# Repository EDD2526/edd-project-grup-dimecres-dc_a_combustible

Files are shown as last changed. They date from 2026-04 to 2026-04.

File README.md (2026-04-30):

View this project on [CADLAB.io](https://cadlab.io/project/30189). 

# Projecte Combustible

>**Autors:** David Puges & Victor Donet
>**Versió: ** v.1.0.0 11/03/2026

----------

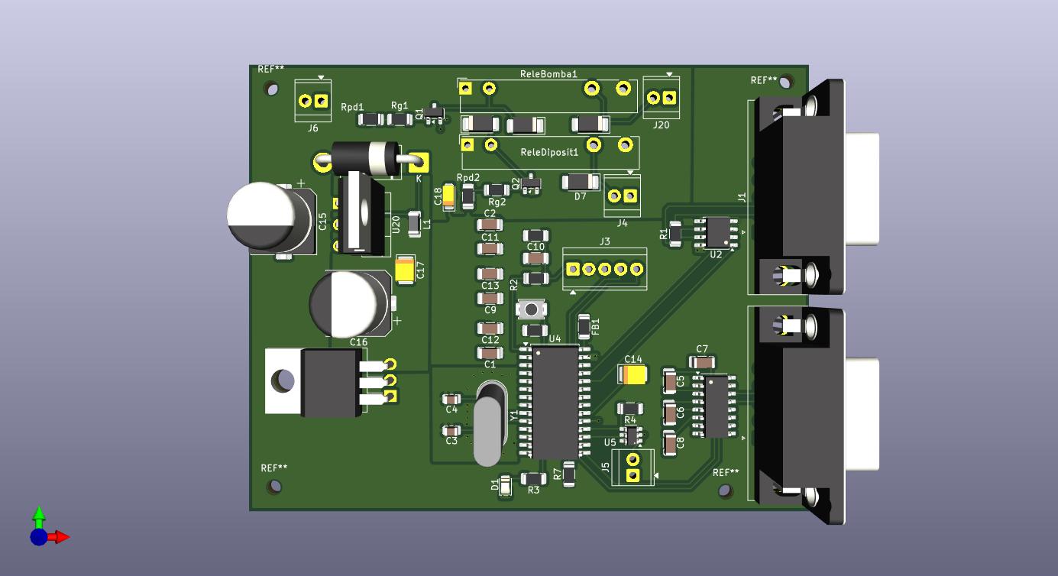
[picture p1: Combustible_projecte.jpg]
PCB 3D Render

*3D render of the Fuel Management Electronic Module designed in KiCad 9. 
The board integrates a PIC24HJ128GP502 microcontroller, CAN bus (MCP2562), 
RS232 (MAX3232), 12-bit I2C DAC (MCP4725), two 12V/6A power relays and a 
complete power management stage (buck LM2596 + LDO LM1117).*

----------
## Objectiu Descripció breu de l'objectiu del projecte.

L'objectiu del projecte és crear una pcb capaç de controlar el mecanisme de tancament de dipòsit del combustible d'un cotxe, controli el sensor de pressió de pneumàtics i el sensor digital de nivell de combustible i el funcionament de la bomba de combustible.

## Diagrama de blocs

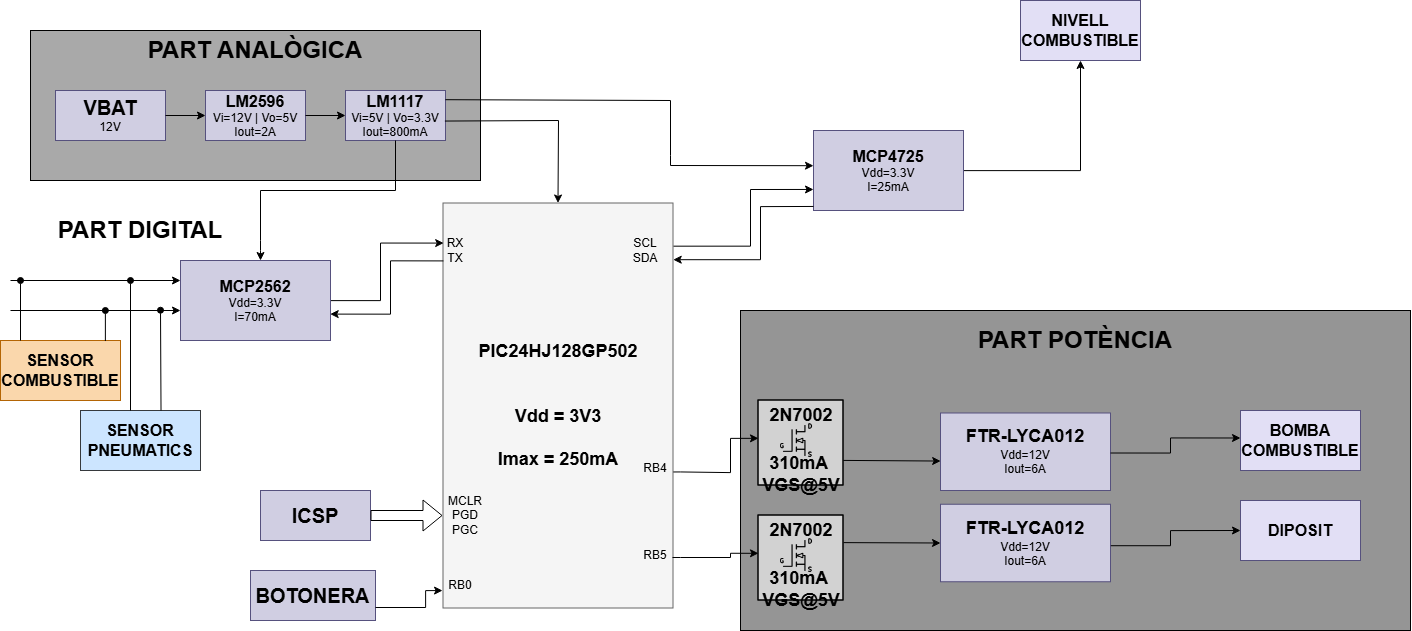
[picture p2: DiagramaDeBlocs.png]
Imatge Diagrama De Blocs


-----------

## Requisits / Especificacions

  - Una etapa regulador de tensió per alimentar tots el components de la placa.
  - Tenir un microcontrolador encarregat del control de la nostra placa.
  - Tenir una connexió BUS CAN, I2C.
  - Una comuniació USART per connectar el microcontrolador a aparells extern ja ve sigui un ordinador.
  - Tenir entrades com un boto per a que s'interección amb la placa.

-----------

## Components

| Descripci&#243; | Ref | Package |Datasheet | Prove&#239;dor | Unitats |
| --- | --- | --- | --- | --- | --- |
| Microcontrolador | PIC24HJ128GP502 | SOIC-28 |[Datasheet](https://ww1.microchip.com/downloads/aemDocuments/documents/OTH/ProductDocuments/DataSheets/70293G.pdf) | Mouser| 1x |
| XTAL-Ressonador | X49SM8MSD2SC | SMD |[Datasheet](https://www.lcsc.com/datasheet/C326536.pdf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) | [LCSC] | 1x |
| Regulador de tensió | LM1117 | SOT-223 | [Enllaç](https://www.ti.com/lit/ds/symlink/lm1117.pdf) | Mouser | 1 |
| Regulador de commutació | LM2596 | TO-220 / TO-263 | [Enllaç](https://www.ti.com/lit/ds/symlink/lm2596.pdf) |Mouser | 1 |
| Transceptor CAN | MCP2557 | SOIC-8  | [Enllaç](https://www.digikey.es/es/products/detail/microchip-technology/MCP2557FD-H-SN/6009299?productid=6009299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) | DigiKey | 1 |
| Convertidor DAC | MCP4725 | SOT-23-6 | [Enllaç](https://ww1.microchip.com/downloads/en/devicedoc/22039d.pdf) | DigiKey / Mouser | 1 |
| Relé | Fujitsu_FTR-LYAA005Y | SPST-Vertical | [Enllaç](https://www.fujitsu.com/sg/imagesgig5/ftr-ly.pdf) | Mouser | 2 |
| Díode protector | PMEG6030EP | Diode_SMD:D_SOD-128 | [Enllaç](https://www.vishay.com/docs/88516/1n5400.pdf) | Mouser | 2 |
| Pulsador reset | SKRKAEE020 | SW_Push_SPST_NO_Alps_SKRK | [Enllaç](https://www.mouser.es/datasheet/2/15/SKRK-1370789.pdf) | Mouser | 1 |
| Connector DB9 | DB9 PINS | DSUB-9 THT | [Enllaç](https://www.we-online.com/components/products/datasheet/61800925123.pdf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) | Digikey | 1 |
| Connector 01x02 | 61300211121 | PinHeader_1x02_P2.54mm_Vertical | [Enllaç](https://www.we-online.com/components/products/datasheet/61300211121.pdf) |Digikey | 4 |
| Connector ISCP | 61200621621 | PinHeader_2x03_P2.54mm_Vertical | [Enllaç](https://www.we-online.com/components/products/datasheet/61200621621.pdf) | Digikey | 1 |
| Connector Usart | 61300611121 | PinHeader_1x06_P2.54mm_Vertical | [Enllaç](https://www.we-online.com/components/products/datasheet/61300611121.pdf) | Digikey | 1 |
-----------

### Eines:

  * KiCad 9.0 o superior 

### Funcionalitats:

  - El mecanisme de tancament i obertura del dipòsit de combustible
  - Un sensor digital del nivell de combustible
  - El mecanisme que controli la bomba de combustible
  - Un sensor que ens avisi quan la pressió dels pneumàtics sigui baixa 

-----------

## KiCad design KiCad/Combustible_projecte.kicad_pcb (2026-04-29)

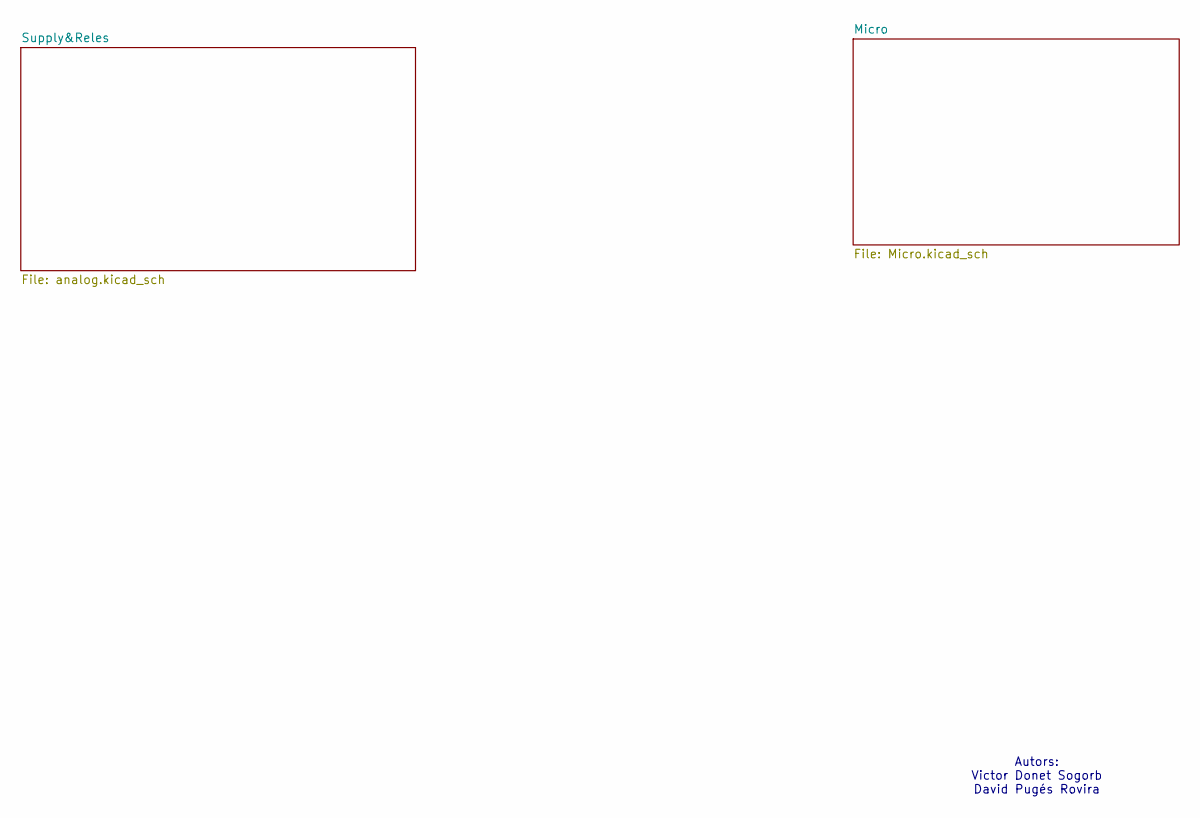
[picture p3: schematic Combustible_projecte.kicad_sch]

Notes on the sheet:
Autors: Victor Donet Sogorb David Pugés Rovira

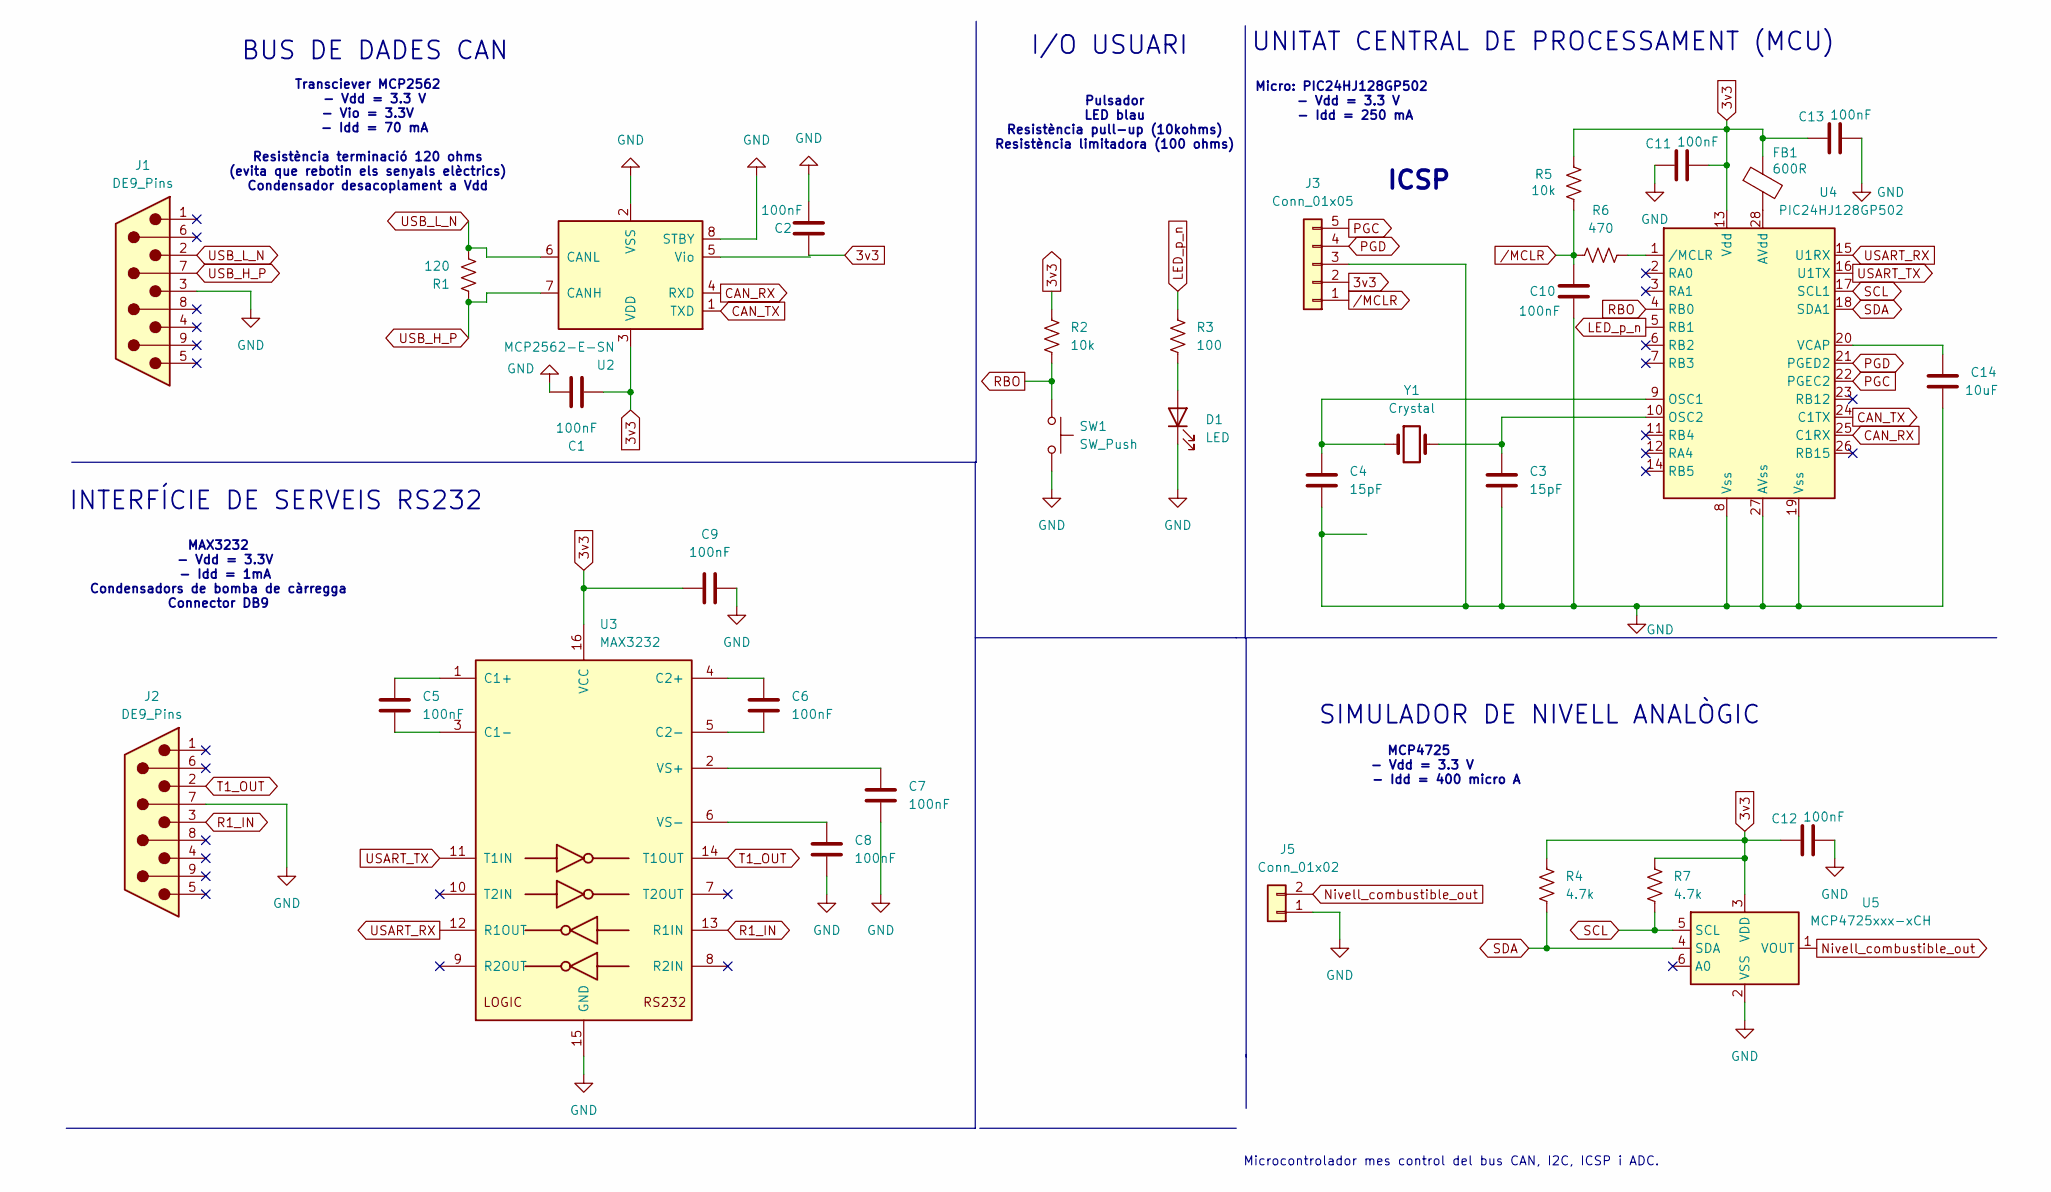
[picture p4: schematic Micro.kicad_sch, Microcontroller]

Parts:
C1, C2, C5, C6, C7, C8, C9, C10, C11, C12, C13: 100nF; C_1206_3216Metric
C3, C4: 15pF; C_0805_2012Metric
C14: 10uF; CP_EIA-3528-12_Kemet-T
D1: LED; LED_0805_2012Metric
FB1: 600R; R_1206_3216Metric
J1, J2: DE9_Pins; DSUB-9_Pins_Horizontal_P2.77x2.84mm_EdgePinOffset4.94mm_Hou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
J3: Conn_01x05; TerminalBlock_TE_282834-5_1x05_P2.54mm_Horizontal
J5: Conn_01x02; TerminalBlock_TE_282834-2_1x02_P2.54mm_Horizontal
R1: 120; R_1206_3216Metric
R2, R5: 10k; R_1206_3216Metric
R3: 100; R_1206_3216Metric
R4, R7: 4.7k; R_1206_3216Metric
R6: 470; R_1206_3216Metric
SW1: SW_Push; SW_Push_SPST_NO_Alps_SKRK
U2: MCP2562-E-SN; SOIC-8_3.9x4.9mm_P1.27mm
U3: MAX3232; SOIC-16_3.9x9.9mm_P1.27mm
U4: PIC24HJ128GP502; SOIC-28W_7.5x17.9mm_P1.27mm
U5: MCP4725xxx-xCH; SOT-23-6
Y1: Crystal; Crystal_HC49-U_Vertical

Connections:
3v3: C1.1, C2.2, C9.1, C11.2, C12.1, C13.1, FB1.1, J3.2, R2.1, R4.1, R5.2, R7.1, U2.3 (VDD), U2.5 (Vio), U3.16 (VCC), U4.13 (Vdd), U5.3 (VDD); also elsewhere on the board
CAN_H: J1.7, R1.1, U2.7 (CANH)
CAN_L: J1.2, R1.2, U2.6 (CANL)
CAN_RX: U2.4 (RXD), U4.25 (C1RX)
CAN_TX: U2.1 (TXD), U4.24 (C1TX)
GND: C1.2, C2.1, C3.2, C4.2, C7.2, C8.2, C9.2, C10.1, C11.1, C12.2, C13.2, C14.2, D1.1 (K), J1.3, J2.7, J3.3, J5.1, SW1.2, U2.2 (VSS), U2.8 (STBY), U3.15 (GND), U4.8 (Vss), U4.19 (Vss), U4.27 (AVss), U5.2 (VSS); also elsewhere on the board
LED_p_n: R3.1, U4.5 (RB1)
unnamed: D1.2 (A), R3.2
unnamed: C5.1, U3.1 (C1+)
unnamed: C5.2, U3.3 (C1-)
unnamed: C6.1, U3.4 (C2+)
unnamed: C6.2, U3.5 (C2-)
unnamed: C7.1, U3.2 (VS+)
unnamed: C8.1, U3.6 (VS-)
unnamed: FB1.2, U4.28 (AVdd)
unnamed: C4.1, U4.9 (OSC1), Y1.1
unnamed: C3.1, U4.10 (OSC2), Y1.2
unnamed: C14.1, U4.20 (VCAP)
unnamed: R6.2, U4.1 (/MCLR)
Nivell_combustible_out: J5.2, U5.1 (VOUT)
PGC: J3.5, U4.22 (PGEC2)
PGD: J3.4, U4.21 (PGED2)
R1_IN: J2.3, U3.13 (R1IN)
RBO: R2.2, SW1.1, U4.4 (RB0)
SCL: R7.2, U4.17 (SCL1), U5.5 (SCL)
SDA: R4.2, U4.18 (SDA1), U5.4 (SDA)
T1_OUT: J2.2, U3.14 (T1OUT)
USART_RX: U3.12 (R1OUT), U4.15 (U1RX)
USART_TX: U3.11 (T1IN), U4.16 (U1TX)
/MCLR: C10.2, J3.1, R5.1, R6.1

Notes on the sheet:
I/O USUARI
BUS DE DADES CAN
UNITAT CENTRAL DE PROCESSAMENT (MCU)
MAX3232 - Vdd = 3.3V - Idd = 1mA Condensadors de bomba de càrregga Connector DB9
Microcontrolador mes control del bus CAN, I2C, ICSP i ADC.
MCP4725 - Vdd = 3.3 V - Idd = 400 micro A
Transciever MCP2562 - Vdd = 3.3 V - Vio = 3.3V - Idd = 70 mA Resistència terminació 120 ohms (evita que rebotin els senyals elèctrics) Condensador desacoplament a Vdd
SIMULADOR DE NIVELL ANALÒGIC
Micro: PIC24HJ128GP502 - Vdd = 3.3 V - Idd = 250 mA
ICSP
INTERFÍCIE DE SERVEIS RS232
Pulsador LED blau Resistència pull-up (10kohms) Resistència limitadora (100 ohms)

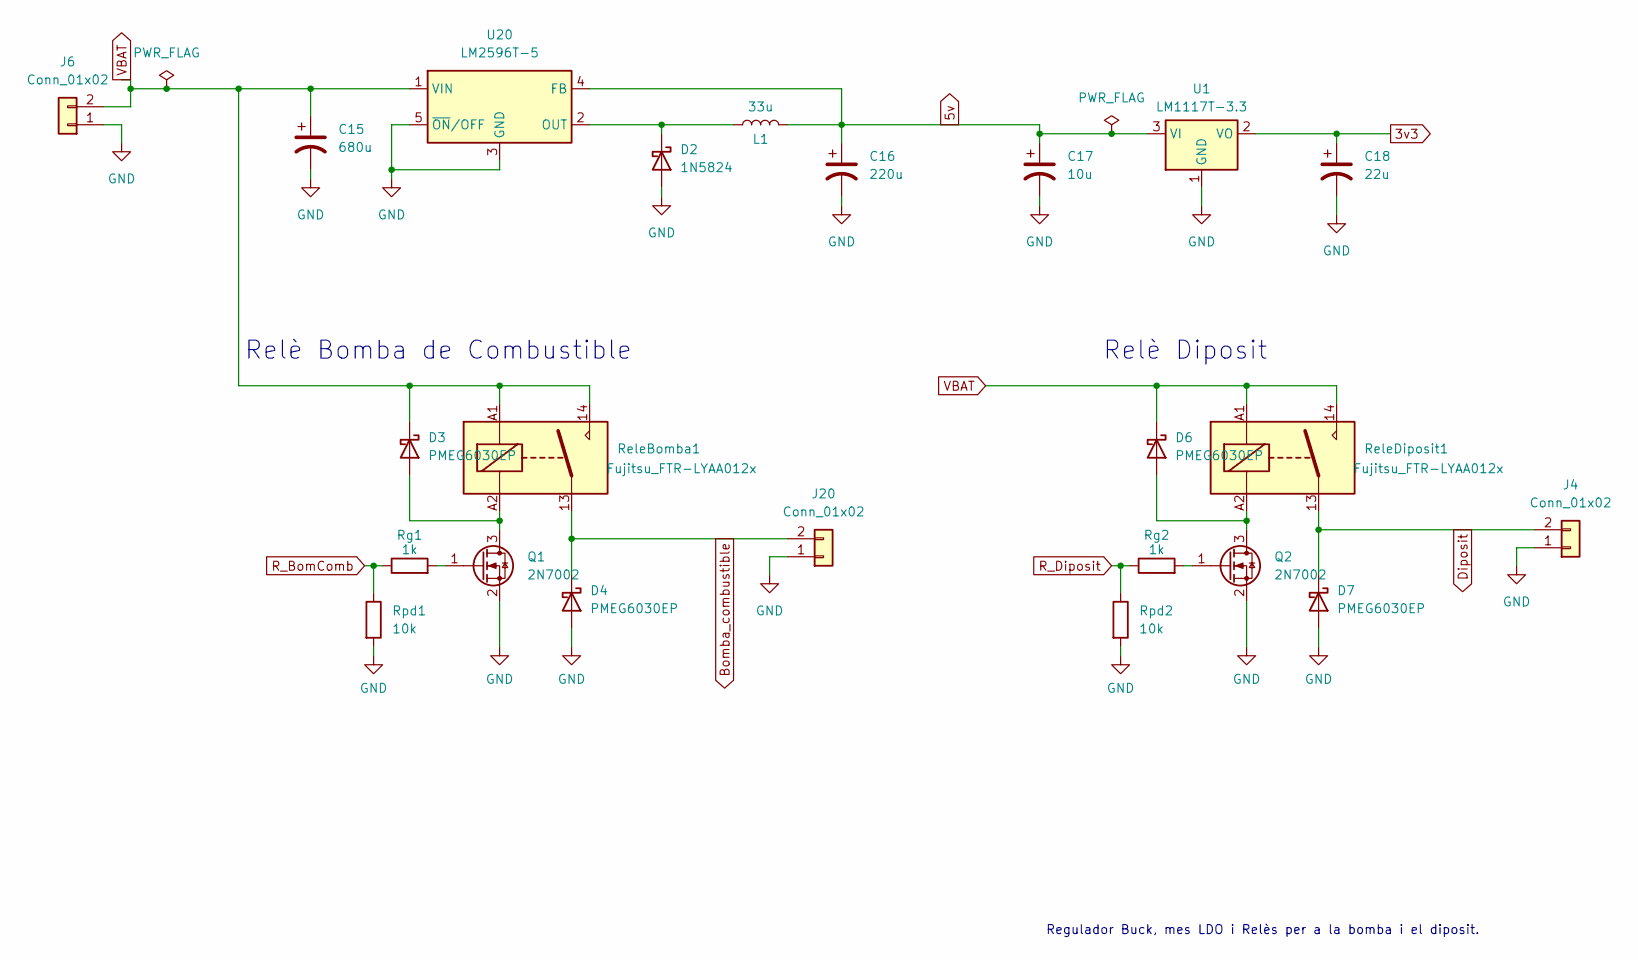
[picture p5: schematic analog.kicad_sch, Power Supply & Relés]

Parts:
C15: 680u; CP_Elec_10x10
C16: 220u; CP_Elec_10x10
C17: 10u; CP_EIA-3528-12_Kemet-T
C18: 22u; CP_EIA-3216-12_Kemet-S
D2: 1N5824; D_DO-201AD_P15.24mm_Horizontal
D3, D4, D6, D7: PMEG6030EP; D_SOD-128
J4, J6, J20: Conn_01x02; TerminalBlock_TE_282834-2_1x02_P2.54mm_Horizontal
L1: 33u; L_1206_3216Metric
Q1, Q2: 2N7002; SOT-23
ReleBomba1: Fujitsu_FTR-LYAA012x; Relay_SPST-NO_Fujitsu_FTR-LYAA005x_FormA_Vertical
ReleDiposit1: Fujitsu_FTR-LYAA012x; Relay_SPST-NO_Fujitsu_FTR-LYAA005x_FormA_Vertical
Rg1, Rg2: 1k; R_1206_3216Metric
Rpd1, Rpd2: 10k; R_1206_3216Metric
U1: LM1117T-3.3; TO-220-3_Horizontal_TabDown
U20: LM2596T-5; TO-220-5_P3.4x3.7mm_StaggerOdd_Lead3.8mm_Vertical

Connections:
3v3: C18.1, U1.2 (VO); also elsewhere on the board
5v: C16.1, C17.1, L1.2, U1.3 (VI), U20.4 (FB)
Bomba_combustible: D4.1 (K), J20.2, ReleBomba1.13
Diposit: D7.1 (K), J4.2, ReleDiposit1.13
GND: C15.2, C16.2, C17.2, C18.2, D2.2 (A), D4.2 (A), D7.2 (A), J4.1, J6.1, J20.1, Q1.2 (S), Q2.2 (S), Rpd1.2, Rpd2.2, U1.1 (GND), U20.3 (GND), U20.5 (~ON/OFF); also elsewhere on the board
unnamed: D2.1 (K), L1.1, U20.2 (OUT)
unnamed: D3.2 (A), Q1.3 (D), ReleBomba1.A2
unnamed: D6.2 (A), Q2.3 (D), ReleDiposit1.A2
unnamed: Q1.1 (G), Rg1.2
unnamed: Q2.1 (G), Rg2.2
R_BomComb: Rg1.1, Rpd1.1
R_Diposit: Rg2.1, Rpd2.1
VBAT: C15.1, D3.1 (K), D6.1 (K), J6.2, ReleBomba1.14, ReleBomba1.A1, ReleDiposit1.14, ReleDiposit1.A1, U20.1 (VIN)

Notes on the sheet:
Relè Bomba de Combustible
Regulador Buck, mes LDO i Relès per a la bomba i el diposit.
Relè Diposit

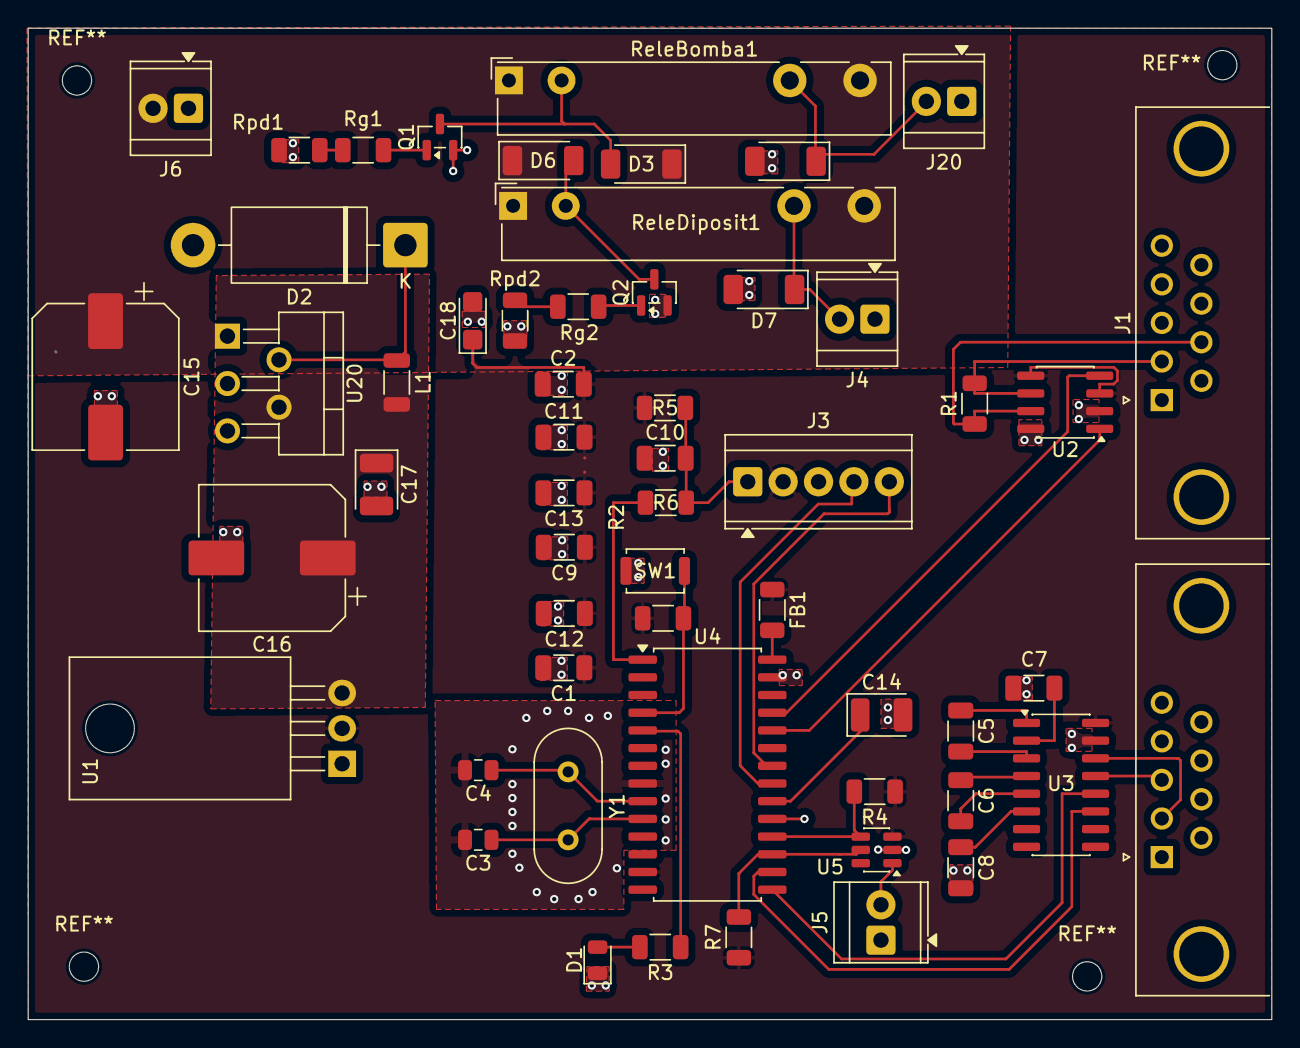
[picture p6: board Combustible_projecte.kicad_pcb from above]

Board: 2 copper layers, 89.2 x 71.2 mm, 56 parts (0 on the bottom side), 41 nets.

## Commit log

2026-03-11 projecte kicad creat
    [Combustible_projecte.kicad_pcb, Combustible_projecte.kicad_sch]
2026-03-11 dibuix micro creat
    [Combustible_projecte.kicad_sch, Micro.kicad_sch]
2026-03-11 Especificat el model de micro
2026-03-16 Afegit el micro i les etapes del bus CAN i USART, també afegit el cristall i el debug
    [Combustible_projecte.kicad_sch, Micro.kicad_sch]
2026-03-17 Afegit el micro, el bus CAN i el USART
2026-03-17 Feta la part digital del micro
    [Micro.kicad_sch]
2026-03-17 Afegida l'etapa digital i el micro
2026-03-17 Part Analogica i Buck fet, falta regulador LDO lineal
    [Combustible_projecte.kicad_sch, analog.kicad_sch]
2026-03-17 millora etapa micro
    [Micro.kicad_sch]
2026-03-17 Regulador LDO fet, part analogica finalitzada
2026-03-17 millora micro
2026-03-17 neteja de fitxers temporals de kicad
2026-03-17 millora disseny micro
    [Micro.kicad_sch]
2026-03-17 Part de potencia acabada, concretar certs pins del micro
    [Combustible_projecte.kicad_sch, analog.kicad_sch, potencia.kicad_sch]
2026-03-18 Arreglat els pins i cambiat el model del relé
    [Micro.kicad_sch, potencia.kicad_sch]
2026-03-21 canvi del micro i millora
    [Micro.kicad_sch]
2026-03-21 micro canviat i millorat
2026-03-24 Part de potencia moguda al sheet de analogica, esborrat el sheet de potencia
    [Combustible_projecte.kicad_sch, Micro.kicad_sch, analog.kicad_sch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]
2026-03-24 Errores ERC corregidos, instanciaciones arregladas
    [Micro.kicad_sch, analog.kicad_sch]
2026-03-24 millora del micro
    [Micro.kicad_sch]
2026-03-24 canvi d'etiquetes
    [analog.kicad_sch]
2026-03-25 Sheets nombrades amb titol, i part del supply millorada
    [Combustible_projecte.kicad_sch, Micro.kicad_sch, analog.kicad_sch]
2026-03-25 sheets editades
    [Micro.kicad_sch, analog.kicad_sch]
2026-04-05 Totes les footprints seleccionades, part de potencia, placement realitzat
    [Combustible_projecte.kicad_pcb, Micro.kicad_sch, analog.kicad_sch]
2026-04-06 Actualització fitxers kicad
    [Micro.kicad_sch, analog.kicad_sch]
2026-04-07 PnR Final versió 1
    [Combustible_projecte.kicad_pcb, Micro.kicad_sch]
2026-04-07 PnR Final versió 2, VBAT i 5V afegit
    [Combustible_projecte.kicad_pcb]
2026-04-07 pista de 5 volts incluida
    [Combustible_projecte.kicad_pcb]
2026-04-08 pnr editat
    [Combustible_projecte.kicad_pcb, Micro.kicad_sch, analog.kicad_sch]
2026-04-12 millora routing
    [Combustible_projecte.kicad_pcb]
2026-04-14 millora pcb
    [Combustible_projecte.kicad_pcb]
2026-04-14 millora illa de coure a gnd
    [Combustible_projecte.kicad_pcb]
2026-04-15 millora vies gnd
    [Combustible_projecte.kicad_pcb]
2026-04-15 pcb bastant canviada i actualitzada
    [Combustible_projecte.kicad_pcb]
2026-04-24 Rotuing acabat? falta les regles del fabricant
    [Combustible_projecte.kicad_pcb]
2026-04-29 Ultims canvis i completat el README
    [Combustible_projecte.kicad_pcb, analog.kicad_sch]
